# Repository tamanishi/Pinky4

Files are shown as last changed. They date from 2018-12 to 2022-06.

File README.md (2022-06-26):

# Pinky4

> **Warning**  
> If you are using Kicad 6, please see https://github.com/tamanishi/Pinky4/issues/4 .

A split 4 x 7 vertically staggered keys and 4 thumb keys keyboard.  
An idea is inspired from [crkbd](https://github.com/foostan/crkbd), [Lily58](https://github.com/kata0510/Lily58), [Ergo42](https://github.com/Biacco42/Ergo42) and [Helix](https://github.com/MakotoKurauchi/helix).  
Pinky4 is designed for PoC.

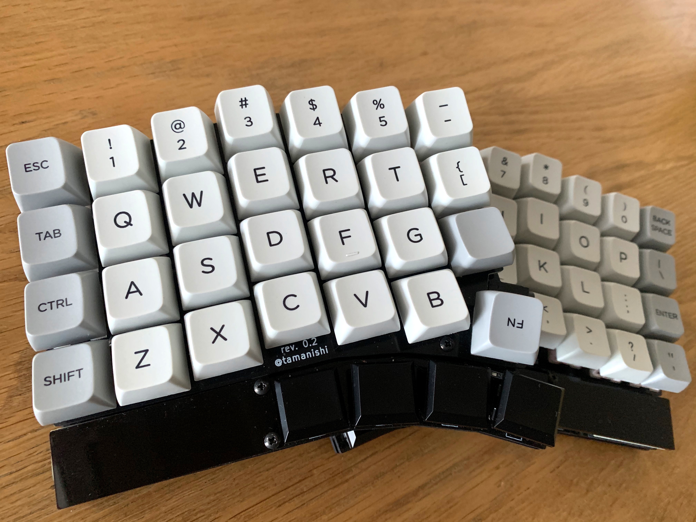
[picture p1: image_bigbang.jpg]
image_bigbang

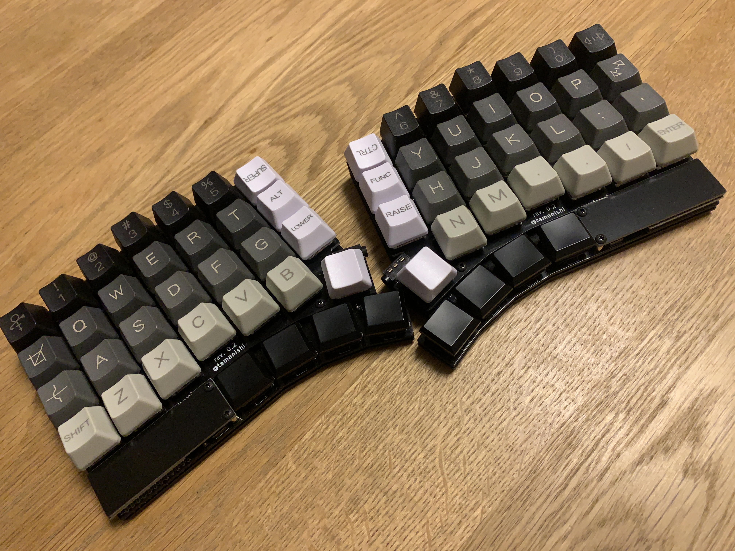
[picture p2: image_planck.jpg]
image_planck

image_grabbag

# Pcb & Plates
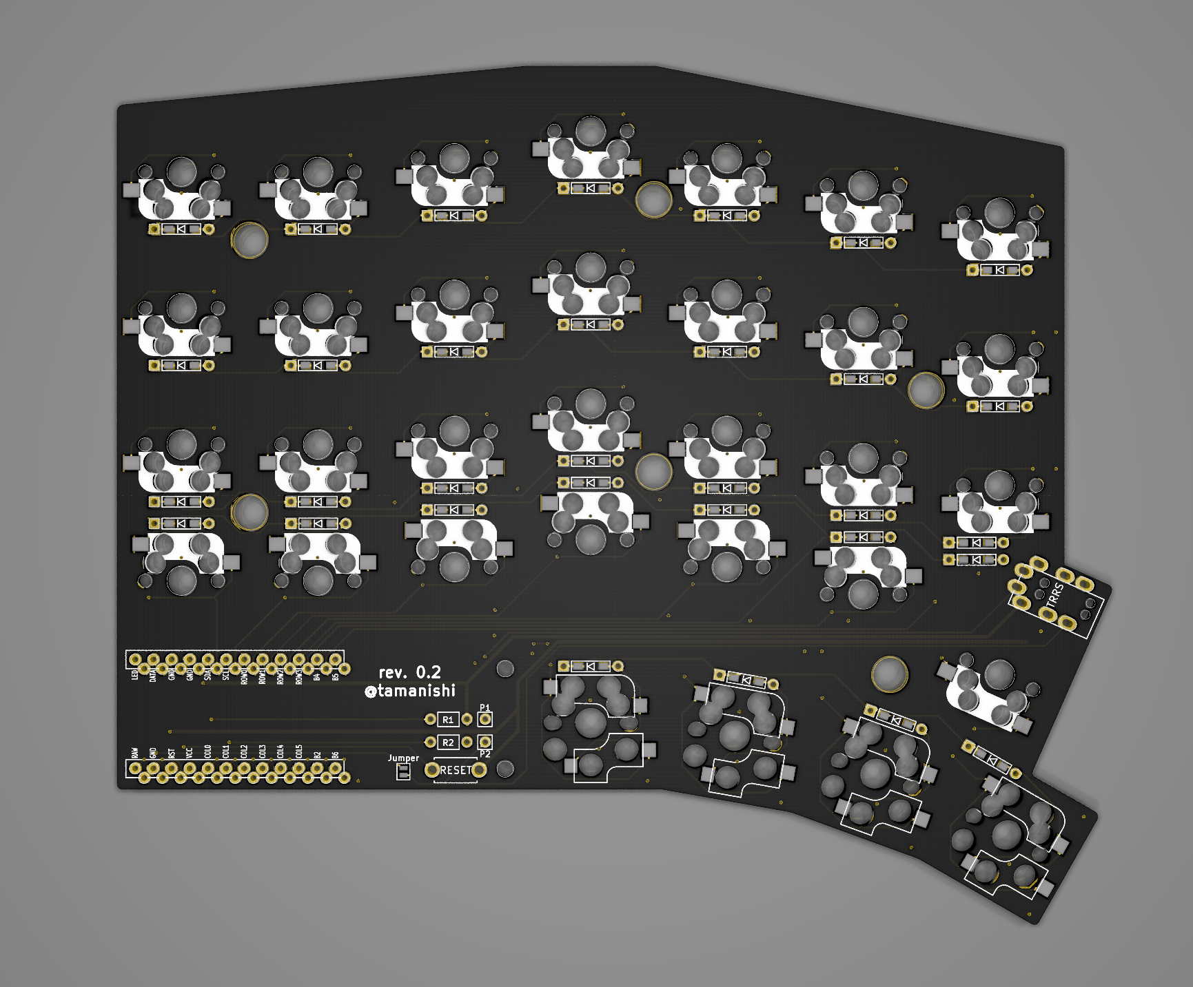
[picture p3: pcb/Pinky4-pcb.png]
pcb

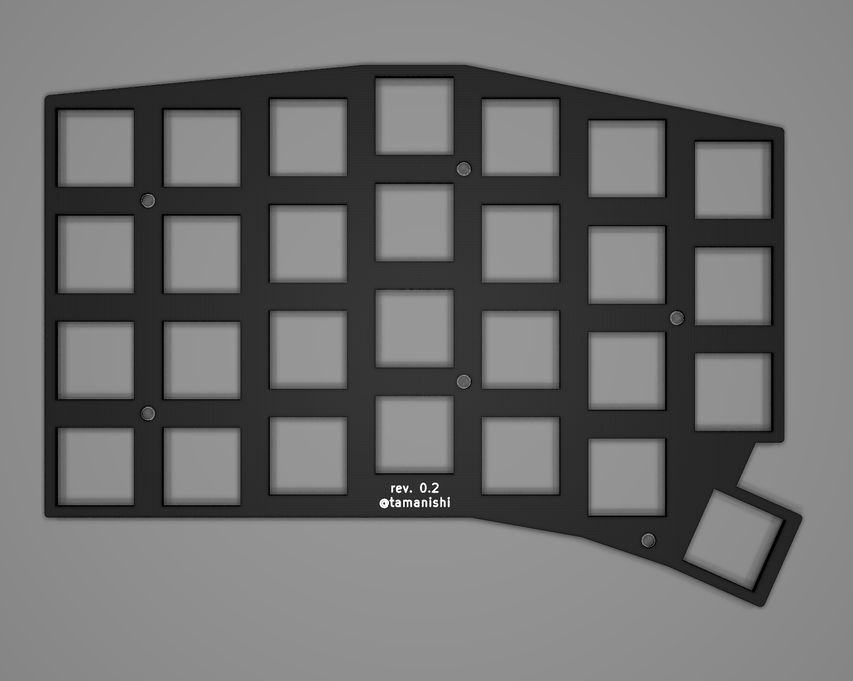
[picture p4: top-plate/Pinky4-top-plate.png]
top plate

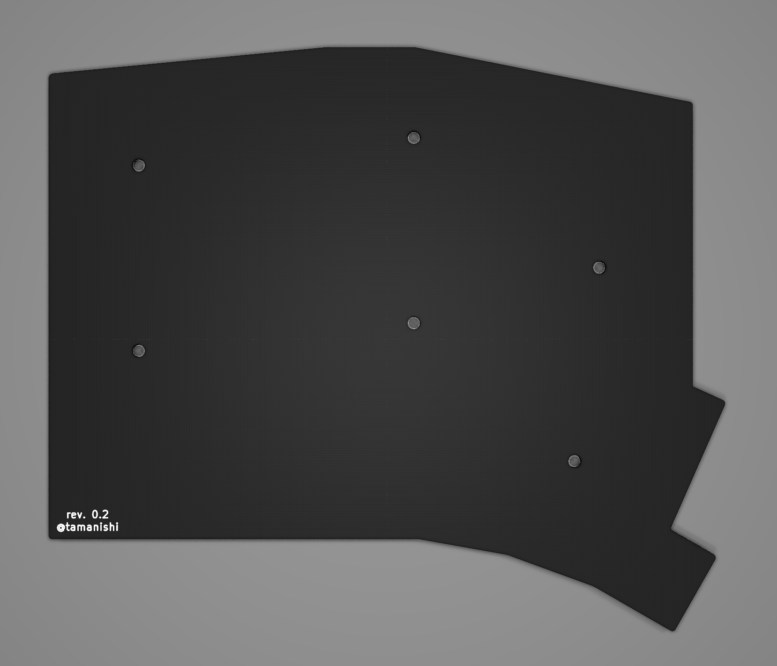
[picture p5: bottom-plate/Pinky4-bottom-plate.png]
bottom plate


# Bill of Materials (for both hands)
| # | name | qty |
| ---: | :--- | ---: |
| 1 | pcbs | 2 |
| 2 | top plates | 2 |
| 3 | bottom plates | 2 |
| 4 | Pro Micros | 2 |
| 5 | 2 pins tact switches | 2 |
| 6 | TRRS connectors | 2 |
| 7 | diodes (1N4148 or 1N4148W) | 64 |
| 8 | Kailh PCB Sockets (MX Sockets) | 56 |
| 9 | Kailh PCB Sockets (Choc Sockets) | 8 |
| 10 | Cherry MX compatible keyswitches | 56 |
| 11 | Kailh low profile (Choc) keyswitches | 8 |
| 12 | Cherry MX compatible keycaps | 56 |
| 13 | Kailh low profile (Choc) compatible keycaps | 8 |
| 14 | TRS or TRRS cable | 1 |
| 15 | 7mm M2 standoffs (for top and bottom plates) | 12 |
| 16 | 5mm M2 standoffs (for Pro Micro cover plates) | 4 |
| 17 | 4mm M2 screws | 32 |
| 18 | rubber cushions | 8 |

# Notes
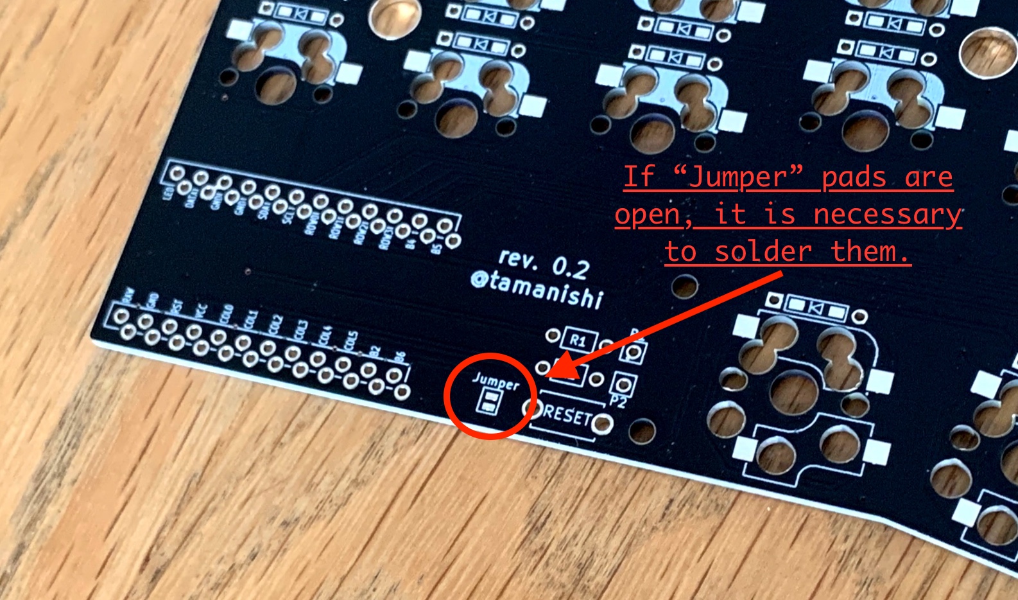
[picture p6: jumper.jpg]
jumper


# Firmware
See [Quantum Mechanical Keyboard Firmware](https://qmk.fm) and [its Pinky support page](https://github.com/qmk/qmk_firmware/blob/master/keyboards/pinky/readme.md)

## TODOs
- [x] add images
- [x] add BOM
- [ ] add build log

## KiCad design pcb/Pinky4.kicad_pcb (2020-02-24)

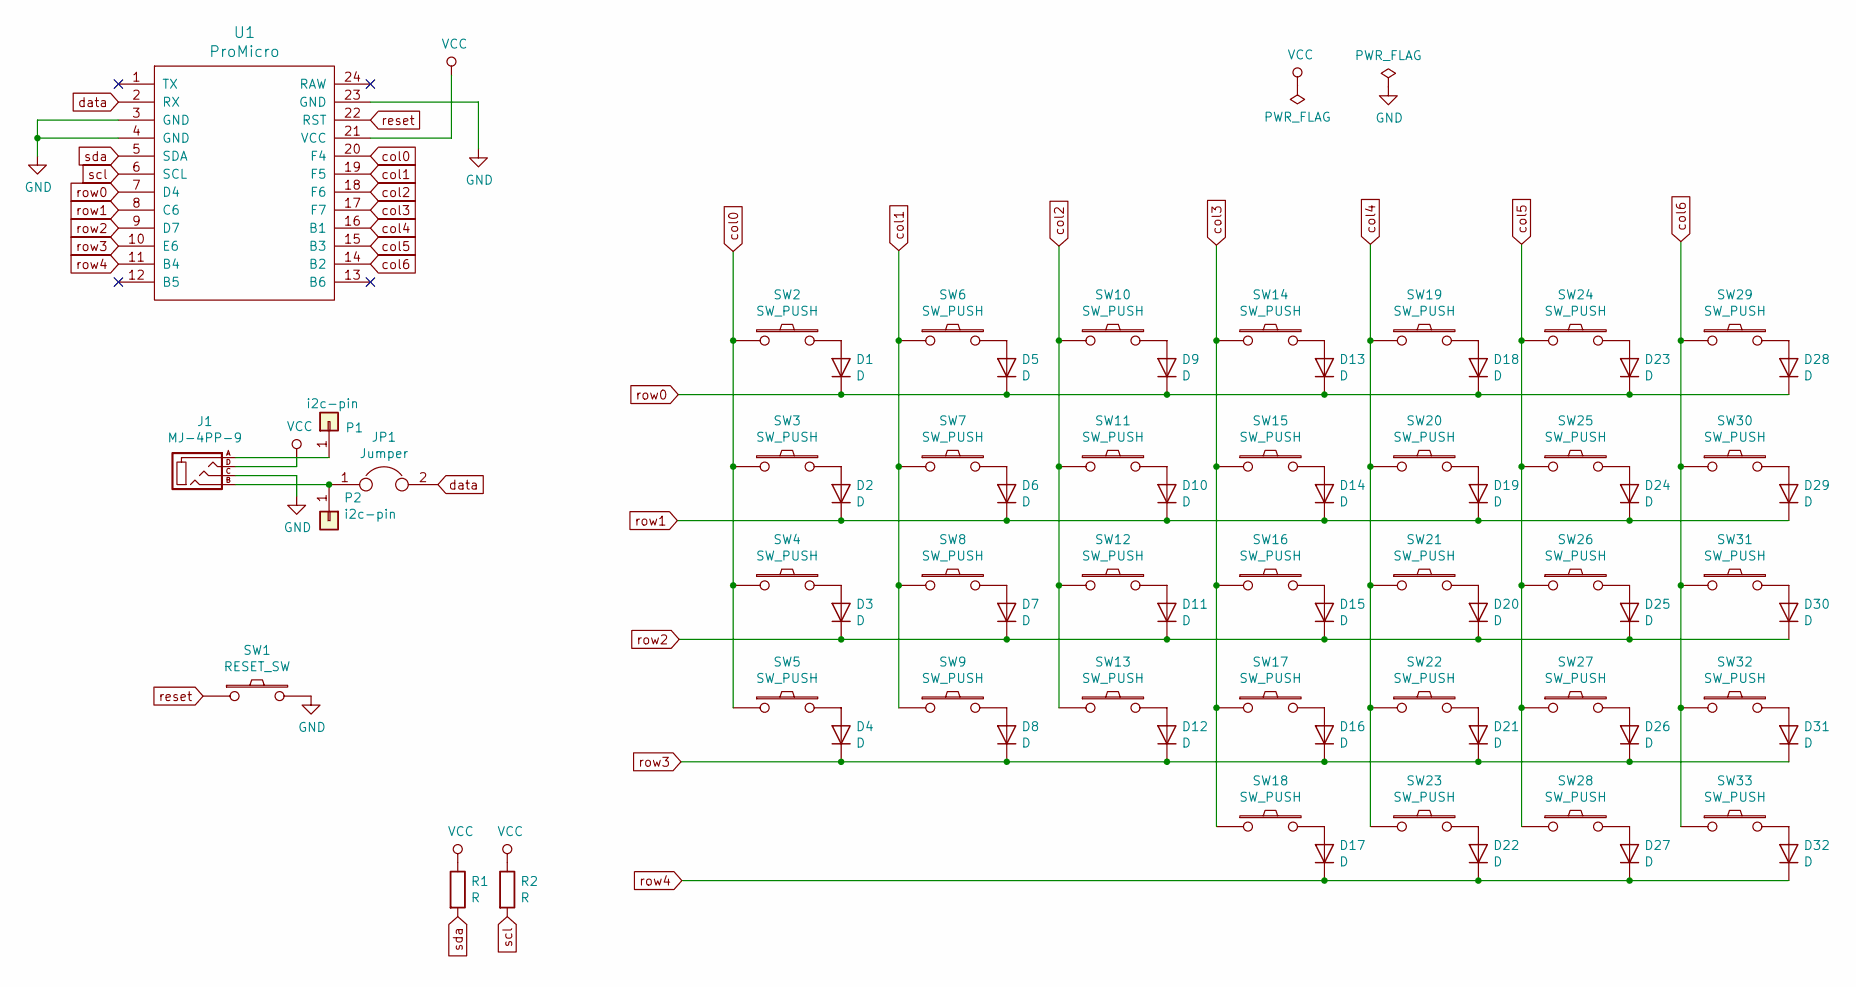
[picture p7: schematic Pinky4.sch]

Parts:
D1, D2, D3, D4, D5, D6, D7, D8, D9, D10, D11, D12, D13, D14, D15, D16, D17, D18, D19, D20, D21, D22, D23, D24, D25, D26, D27, D28, D29, D30, D31, D32: D; D3_TH_SMD
J1: MJ-4PP-9
JP1: Jumper
P1, P2: i2c-pin; 1pin_conn
R1, R2: R
SW1: RESET_SW; ResetSW
SW2, SW3, SW4, SW5, SW6, SW7, SW8, SW9, SW10, SW11, SW12, SW13, SW14, SW15, SW16, SW17, SW19, SW20, SW21, SW22, SW24, SW25, SW26, SW27, SW29, SW30, SW31, SW32: SW_PUSH; CherryMX_Hotswap
SW18, SW23, SW28, SW33: SW_PUSH; CherryMX_KailhLowProfile_Hotswap
U1: ProMicro; ProMicro_v2

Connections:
GND: J1.C, SW1.2, U1.3 (GND), U1.4 (GND), U1.23 (GND)
unnamed: D1.2 (A), SW2.2
unnamed: D2.2 (A), SW3.2
unnamed: D3.2 (A), SW4.2
unnamed: D4.2 (A), SW5.2
unnamed: D5.2 (A), SW6.2
unnamed: D6.2 (A), SW7.2
unnamed: D7.2 (A), SW8.2
unnamed: D8.2 (A), SW9.2
unnamed: D9.2 (A), SW10.2
unnamed: D10.2 (A), SW11.2
unnamed: D11.2 (A), SW12.2
unnamed: D12.2 (A), SW13.2
unnamed: D13.2 (A), SW14.2
unnamed: D14.2 (A), SW15.2
unnamed: D15.2 (A), SW16.2
unnamed: D16.2 (A), SW17.2
unnamed: D17.2 (A), SW18.2
unnamed: D18.2 (A), SW19.2
unnamed: D19.2 (A), SW20.2
unnamed: D20.2 (A), SW21.2
unnamed: D21.2 (A), SW22.2
unnamed: D22.2 (A), SW23.2
unnamed: D23.2 (A), SW24.2
unnamed: D24.2 (A), SW25.2
unnamed: D25.2 (A), SW26.2
unnamed: D26.2 (A), SW27.2
unnamed: D27.2 (A), SW28.2
unnamed: D28.2 (A), SW29.2
unnamed: D29.2 (A), SW30.2
unnamed: D30.2 (A), SW31.2
unnamed: D31.2 (A), SW32.2
unnamed: D32.2 (A), SW33.2
unnamed: J1.B, JP1.1, P2.1
col0: SW2.1, SW3.1, SW4.1, SW5.1, U1.20 (F4)
col1: SW6.1, SW7.1, SW8.1, SW9.1, U1.19 (F5)
col2: SW10.1, SW11.1, SW12.1, SW13.1, U1.18 (F6)
col3: SW14.1, SW15.1, SW16.1, SW17.1, SW18.1, U1.17 (F7)
col4: SW19.1, SW20.1, SW21.1, SW22.1, SW23.1, U1.16 (B1)
col5: SW24.1, SW25.1, SW26.1, SW27.1, SW28.1, U1.15 (B3)
col6: SW29.1, SW30.1, SW31.1, SW32.1, SW33.1, U1.14 (B2)
data: JP1.2, U1.2 (RX)
reset: SW1.1, U1.22 (RST)
row0: D1.1 (K), D5.1 (K), D9.1 (K), D13.1 (K), D18.1 (K), D23.1 (K), D28.1 (K), U1.7 (D4)
row1: D2.1 (K), D6.1 (K), D10.1 (K), D14.1 (K), D19.1 (K), D24.1 (K), D29.1 (K), U1.8 (C6)
row2: D3.1 (K), D7.1 (K), D11.1 (K), D15.1 (K), D20.1 (K), D25.1 (K), D30.1 (K), U1.9 (D7)
row3: D4.1 (K), D8.1 (K), D12.1 (K), D16.1 (K), D21.1 (K), D26.1 (K), D31.1 (K), U1.10 (E6)
row4: D17.1 (K), D22.1 (K), D27.1 (K), D32.1 (K), U1.11 (B4)
scl: R2.2, U1.6 (SCL)
sda: R1.2, U1.5 (SDA)

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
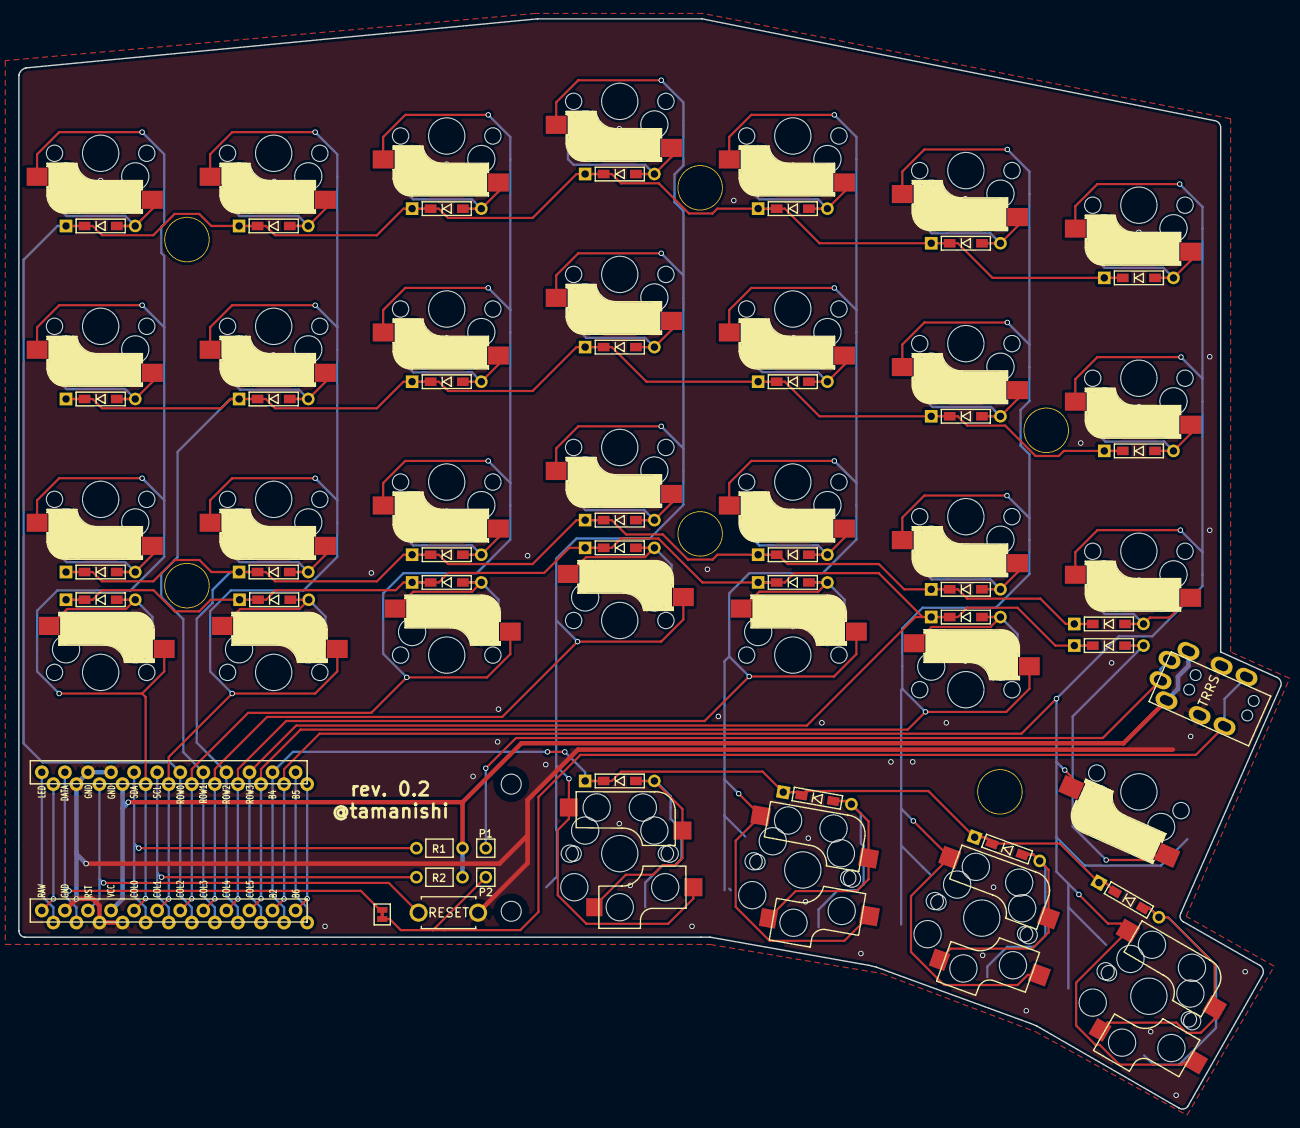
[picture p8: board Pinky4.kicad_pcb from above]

Board: 2 copper layers, 139.0 x 120.0 mm, 80 parts (0 on the bottom side), 52 nets.

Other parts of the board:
HOLE_M2, HOLE_M2#2: VAL**; HOLE_M2
Ref**: Val**; HOLE
Ref**#2, Ref**#3, Ref**#4, Ref**#5, Ref**#6: Val**; HOLE

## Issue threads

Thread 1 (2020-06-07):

Confusing note about jumper

nutttty, 2020-06-07:
The jumper note starts with "If not," but there's no context. Under what circumstance should the jumper be soldered?

cathos, 2020-06-08:
I'm confused about it as well. I messaged awhile ago, but did not open an issue.

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

tamanishi, 2020-06-13:
Hi.
I'm sorry for my poor English.

I replaced the note.
"If "Jumper" pads are open, it is necessary to solder them."

I hope this has a clearer meaning.

nutttty, 2020-06-14:
That makes it clear! Thanks!

Closed 2020-06-14.

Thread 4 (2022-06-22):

Wrong Junction/Short in Schematic

BluPhoenix, 2022-06-22:
There is a Junction at the J1 connector shorting the A (Data) and D (VCC) inputs.
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

tamanishi, 2022-06-25:
Thanks for your comment.

I checked with Kicad 5 on my mac and it was not short-circuited. It wasn't connected in PCB Editor either.
(Check the images below).

And when I checked it in Kicad 6, it was shorted in Schematic Editor and not connected in PCB Editor as you said.

I guess the problem is caused by Kicad 6.

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

tamanishi, 2022-06-26:
The Kicad developer says that in Kicad 6, this is "as-designed" behavior. Sorry for the inconvenience, please use Kicad 5 for a while.
https://gitlab.com/kicad/code/kicad/-/issues/10235
https://gitlab.com/kicad/code/kicad/-/issues/11760
https://gitlab.com/kicad/code/kicad/-/issues/11831

BluPhoenix, 2022-06-26:
Hi thanks for the quick replies. Kind of weird of KiCAD to introduce an update that potentially changes connectivity.
For myself I'd simply move the VCC symbol a bit and remove the junction and then use KiCAD 6.

Just wanted to inform people of this issue before someone unknowingly updates the PCB Components and nets from schematic and doesn't notice this.

Closed 2022-08-13.

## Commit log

2018-11-04 [WIP] wiring & layouting
    [Pinky.kicad_pcb, Pinky.sch]
2018-11-08 [WIP] layout completed
    [Pinky.kicad_pcb]
2018-11-11 [WIP] wiring
    [Pinky.kicad_pcb]
2018-11-18 finished wiring
    [Pinky.kicad_pcb, Pinky.sch]
2018-11-18 add top plate layer
    [Pinky.kicad_pcb]
2018-11-18 tweaked wiring
    [Pinky.kicad_pcb]
2018-11-23 change direction of some keyswitches and tweak wiring
    [Pinky.kicad_pcb]
2018-11-25 sent to allpcb
    [Pinky-B.Cu.gbr, Pinky-B.Mask.gbr, Pinky-B.SilkS.gbr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]
2018-11-26 0.1mm の精度の設定を全て消したつもり。
    [Pinky-B.Cu.gbr, Pinky-B.Mask.gbr, Pinky-B.SilkS.gbr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]
2018-11-27 confirm 0.1mm hole size
    [Pinky.kicad_pcb]
2018-12-02 remove 0.1mm holes
    [Pinky-B.Cu.gbr, Pinky-B.Mask.gbr, Pinky-B.SilkS.gbr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]
2018-12-03 add HOLE_M2 for promicro cover
    [Pinky.kicad_pcb]
2018-12-06 move promicro outside
    [Pinky.kicad_pcb]
2018-12-09 move thumb keys inside
    [Pinky-B.Cu.gbr, Pinky-B.Mask.gbr, Pinky-B.SilkS.gbr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]
2018-12-10 add plates
    [Pinky-bottom-plate.kicad_pcb, Pinky-top-plate.kicad_pcb]
2018-12-11 add to gitignore plate gerber files
2018-12-28 - readme - rename to Pinky4
    [Pinky4-bottom-plate.kicad_pcb, Pinky4-top-plate.kicad_pcb, Pinky4.kicad_pcb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]
2019-01-19 move trrs layout tweaking to another branch
    [Pinky4.kicad_pcb]
2019-01-19 add pcb image
2019-01-19 add pcb plates images
2019-01-19 update note about jumper soldering.
